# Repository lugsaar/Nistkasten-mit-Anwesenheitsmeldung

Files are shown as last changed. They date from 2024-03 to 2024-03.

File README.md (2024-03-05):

# Nistkasten-mit-Anwesenheitsmeldung
Nistkasten mit LoRaWAN - Nesting Box with LoRaWAN.

Wir wollen im Wald verteilt für die heimischen Vogelarten Nistkästen aufhängen um das Brutverhalten der Vögel unauffällig zu studieren. Wann wird das Nest gebaut, wie entwickeln sich die Jungvögel und wird der Kasten ein zweites Mal belegt. Unser Nistkasten meldet sich über LoRaWAN.  

https://blog.lugsaar.de/posts/2024-02-14-lugposts/

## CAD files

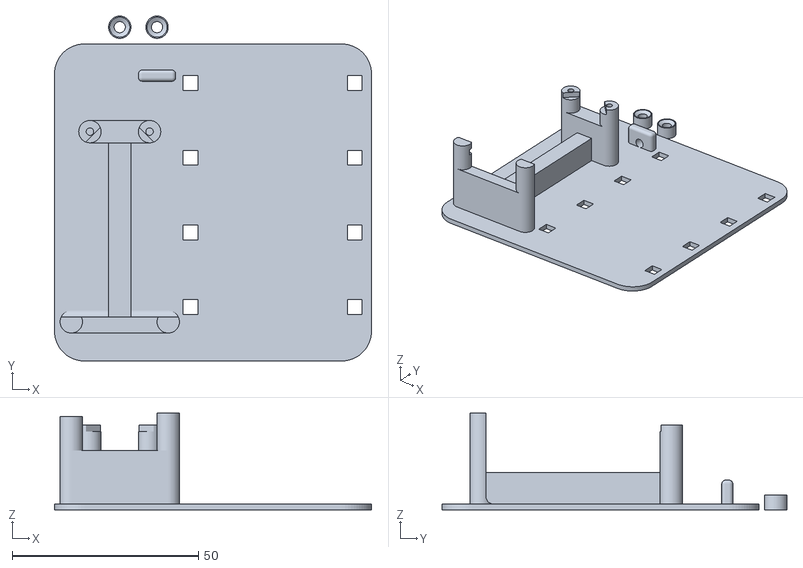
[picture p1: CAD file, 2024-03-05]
3D-printfiles/Heltec_plate_Dose.stl
85.0 x 92.5 x 26.0

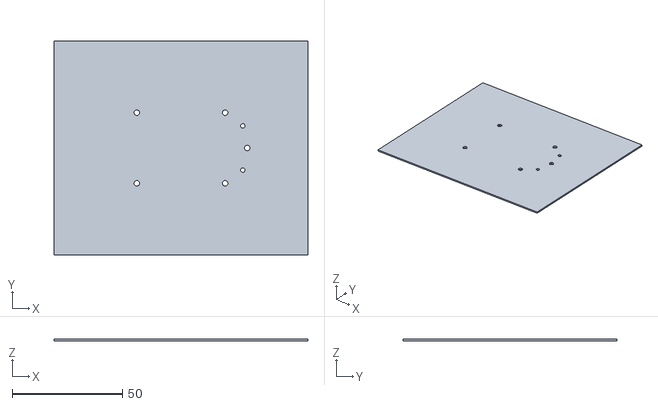
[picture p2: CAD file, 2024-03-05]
3D-printfiles/BohrschablWaegezelle_05.stl
115.0 x 97.0 x 0.8

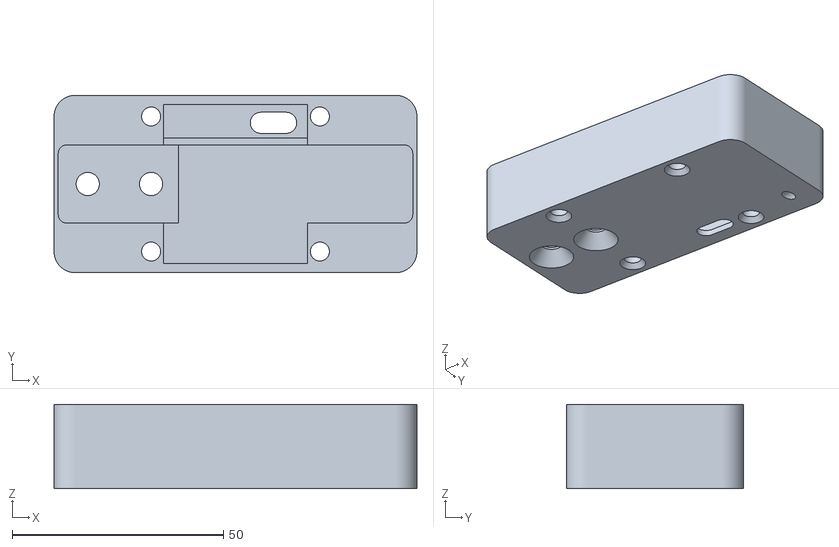
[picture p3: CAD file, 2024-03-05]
3D-printfiles/BodyWaegezelle_05.stl
86.0 x 42.0 x 20.0

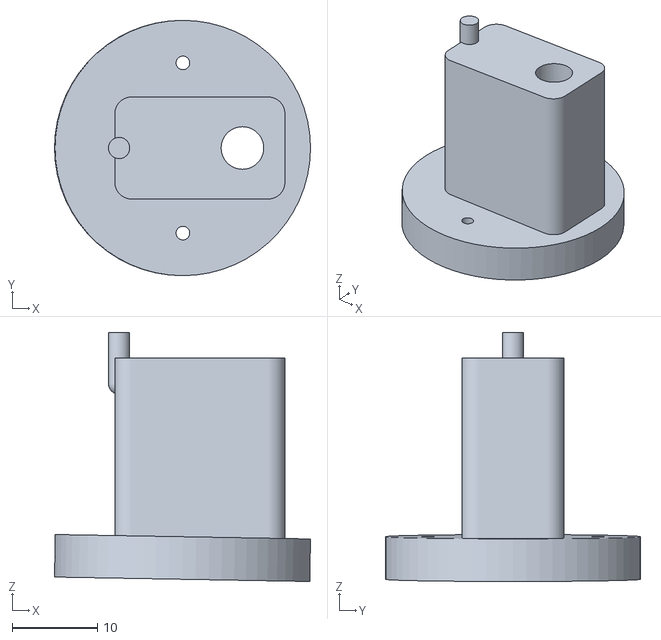
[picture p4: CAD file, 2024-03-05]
3D-printfiles/StuetzeWaegezelle_05.stl
30.1 x 30.0 x 29.3

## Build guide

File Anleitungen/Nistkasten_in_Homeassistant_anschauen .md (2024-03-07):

## So schauen wir uns die Aktivitäten in den Nistkästen in Homeassistant an

#### Einstellungen im TheThingsNetwork

Im TheThingsNetwork finden wir im seitlichen Menü unter Intergrations die Applikation MQTT. Dort wird uns die Serveradresse und der Username angezeigt. In unserem Beispiel waren dies 

    eu1.cloud.thethings.network, Port 1883 und Benutzername nesting@ttn

Mit der Taste generate new API Key erzeugen wir uns das zugehörende Passwort. Nun wechseln wir zu den Live Daten unseres Nistkastens Blaumeisen.

    applikations -> nesting-box-test -> End devices -> blaumeisen -> Live data

und klicken eine der letzten Meldungen an. Es erscheint ein detailierter Json Code. Dort finden wir device_id, application_id und tenant_id.

Um die Devices per mqtt zu abonieren ist die Syntax für den Topic 

    r3/{application id}@{tenant id}/devices, in unserem Fall also r3/nesting@ttn/devices

#### Einstellungen in Homeassistant

In Homeassistant fügen wir die Integration MQTT hinzu. MQTT neu konfigurieren verlangt die oben nachgeschauten Daten Servername, Port, Benutzername und Passwort und unter - auf einen Topic hören - den entsprechenden String.

Jetzt wird die configuration.yaml mit einem Editor manuel angepasst.

In unserer Homeassistant Installation schalten wir in der linken Menüleiste mit Klick auf den Anmeldenamen die erweiterten Optionen frei.
Nun können wir über den Add On Store ssh installieren und in das Terminal wechseln. Die configuration.yaml ist im Verzeichnis config. Wir öffnen sie mit dem Editor nano:

    nano config/configuration.yaml

und ergänzen dieses für unsere beiden Nistkästen.

```
mqtt:
  sensor:
    - name: Rotkehlchen Batterie
      state_topic: "v3/nesting@ttn/devices/rotkehlchen/up"
      value_template: '{{value_json.uplink_message.decoded_payload.batterie_status_in_volt}}'
      unit_of_measurement: "V"
    - name: Rotkehlchen Nestgewicht
      state_topic: "v3/nesting@ttn/devices/rotkehlchen/up"
      value_template: '{{value_json.uplink_message.decoded_payload.nestgewicht_in_gramm}}'
      unit_of_measurement: "g"
    - name: Blaumeisen Batterie
      state_topic: "v3/nesting@ttn/devices/blaumeisen/up"
      value_template: '{{value_json.uplink_message.decoded_payload.batterie_status_in_volt}}'
      unit_of_measurement: "V"
    - name: Blaumeisen Nestgewicht
      state_topic: "v3/nesting@ttn/devices/blaumeisen/up"
      value_template: '{{value_json.uplink_message.decoded_payload.nestgewicht_in_gramm}}'
      unit_of_measurement: "g"
```

Die configuration.yaml ist sehr kritisch bezüglich der richtigen Eingaben und Einrückungen des Codes. Unter 

    Entwicklerwerkzeuge, Reiter YAML -> Konfiguration prüfen 

müssen wir unbedingt feststellen ob wir keinen Fehler gemacht haben, denn dann würde sich Homeassistant nicht mehr starten lassen. 
Wenn alles geklappt hat werden die Nistkästen nach einem Neustart auf der Homeassistant Übersicht auf einer neuen Karte Sensor angezeigt.

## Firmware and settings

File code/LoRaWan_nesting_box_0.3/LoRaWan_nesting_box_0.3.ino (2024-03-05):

/* Nistkasten mit Anwesenheitserkennung
 *
 * Nistkasten mit Heltec WiFi LoRa 32(V3) Node und Wägezelle HX711
 *
 * Funktion:
 * Das Gewicht im Nistkasten wird regelmäßig gemessen
 * und per LoRaWAN an TheThingsNetwork übertragen.
 * An dem Verlauf der Gewichte sehen wir ob und wie
 * der Nistkasten genutzt wird
 * 
 * Ein Projekt der Linux User Group Saar
 * mancas@lug-saar.de
 * dominik@lug-saar.de
 * 
 * 
 * v0.1 neu erstellt
 * v0.2 Kommentare nach DE übersetzt und ergänzt
 * v0.3 Batterie Level auslesen
 */



// Werte für das LoRaWan
// =====================

#include "LoRaWan_APP.h"

// Dies sind die Werte, mit denen unseren Rotkehlchenkasten im TheThingsNetwork angelegt ist
//

//  uint8_t appEui[] = { 0x6E, 0x65, 0x73, 0x74, 0x69, 0x6E, 0x67, 0x0A };
//  uint8_t devEui[] = { 0x70, 0xB3, 0xD5, 0x7E, 0xD0, 0x06, 0x44, 0x73 };
//  uint8_t appKey[] = { 0xBA, 0xC5, 0x2D, 0xAA, 0xEC, 0x79, 0x83, 0x90, 0x9F, 0xC2, 0x56, 0xB7, 0x1C, 0xC0, 0x1D, 0x97 };


// Dies sind die Werte, mit denen unseren Blaumeisenkasten im TheThingsNetwork angelegt ist
// Es wird nur eines der Beispiele geflasht 
// 

 uint8_t appEui[] = { 0x07, 0x00, 0xB3, 0x0D, 0x50, 0x7E, 0x0D, 0x01 };
 uint8_t devEui[] = { 0x70, 0xB3, 0xD5, 0x7E, 0xD0, 0x06, 0x44, 0x90 };
 uint8_t appKey[] = { 0x23, 0x6F, 0xAE, 0x6B, 0x68, 0x2E, 0x5D, 0x26, 0xE9, 0x1A, 0x78, 0xC4, 0x21, 0xC0, 0x0A, 0xD0 };

// Diese ABP Parameter bleiben unverändert
uint8_t nwkSKey[] = { 0x15, 0xb1, 0xd0, 0xef, 0xa4, 0x63, 0xdf, 0xbe, 0x3d, 0x11, 0x18, 0x1e, 0x1e, 0xc7, 0xda,0x85 };
uint8_t appSKey[] = { 0xd7, 0x2c, 0x78, 0x75, 0x8c, 0xdc, 0xca, 0xbf, 0x55, 0xee, 0x4a, 0x77, 0x8d, 0x16, 0xef,0x67 };
uint32_t devAddr =  ( uint32_t )0x007e6ae1;

// LoraWan channelsmask, default channels 0-7*/ 
uint16_t userChannelsMask[6]={ 0x00FF,0x0000,0x0000,0x0000,0x0000,0x0000 };

// LoraWan Region, wird in der Arduiono-IDE bei den Boardeigenschaften gesetzt
LoRaMacRegion_t loraWanRegion = ACTIVE_REGION;

// LoraWan Class, Class A bedeutet nur Senden und kein zeitliches Empfangsfenster öffnen
DeviceClass_t  loraWanClass = CLASS_A;

// Hier wird eingetragen wie oft gesendet wird, Wert in Millisekunden.
// Gemäß Policy dürfen wir nur 1% der Zeit senden. 240000 bedeutet alle 4 Minuten,
// das passt für ein Sendefenster von 2,4 s.
// und ist gut zum Testen. Weniger Energieverbrauch bei nur einer Meldung je Tag 

//uint32_t appTxDutyCycle = 86400000;  // einmal je Tag
//uint32_t appTxDutyCycle = 3600000;  // einmal je Stunde
uint32_t appTxDutyCycle = 240000;      // alle 4 Minuten  

// Wir akzeptieren Auktivierung vom Server
bool overTheAirActivation = true;

// Wir akzeptieren die Adresse von Server
bool loraWanAdr = true;

// Wir senden nur bestätigte Nachrichten
bool isTxConfirmed = true;

// Unser Port
uint8_t appPort = 2;

// Anzahl der Versuche wenn wir keine Bestätigung vom Gateway bekommen
// dabei akzeptieren wir eine Übertragungsreduzierung nach LoRaWAN Specification V1.0.2, chapter 18.4
uint8_t confirmedNbTrials = 4;



// Werte für die Wägezelle
// =======================

#include "HX711.h" //scale
HX711 scale;

uint8_t dataPin = 26;   // Der HX711 dataPin ist am GPIO 26
uint8_t clockPin = 48;  // der HX711 clockPin ist am GPIO 48
int int_nestweight = 0; // Integer-Variable für das Gewicht



// Werte für Auslesen der Batteriespannung
// =======================================

#define VBAT_PIN 1
#define VBAT_READ_CNTRL_PIN 37 // Wir lesen die GPIO aus 
#define ADC_READ_STABILIZE 10 // Wartezeit in ms für die Erfassung

int int_readBatLevel =0; // Variable für die Aufbereitung der payload
float readBatLevel() {
  int analogValue = analogRead(VBAT_PIN);
  float voltage = 0.004376 * analogValue; // Umrechnung der GPIO Werte in Spannung
  return voltage;
}

// Subroutine Aktivieren der Waage und Aufbereiten der Payload
// ===========================================================
static void prepareTxFrame( uint8_t port )
{

// Waage nach dem Energiesparmodus initialisieren  
Serial.begin(115200);

Serial.println("wakeup scale");

scale.begin(dataPin, clockPin); // Anschluss der Kabel übergeben
scale.set_scale(1000.795471);   // Eichwert für leere Waage, wird vorher separat ermittelt, dann eingetragen    
scale.set_offset(4294624289);   // Eichwert für belastete Waage, wird vorher separat ermittelt, dann eingetragen

delay(5000); // Abwarten bis die Waage bereit ist
  
if (scale.is_ready())
  
  {
  Serial.println("scale is ready");
  Serial.println(scale.get_units(1));
  //int_nestweight = abs(scale.get_units(1)*10); // Werte mit einer Nachkommastelle zu Integer aufbereiten nur positive Werte
    int_nestweight = (scale.get_units(1)*10); // Werte mit einer Nachkommastelle zu Integer aufbereiten auch negative Werte
    int_nestweight = 890; //Testwert bei Betrieb ohne Waage 
    if (int_nestweight > 9000) // Werte über 900 g sind Fehlmessungen und werden mit 9999 gekennzeichnet
    {
    int_nestweight = 9999;
    }
  }
  
else
  {
    int_nestweight = 8888; // Die Waage ist nicht bereit, wird mit 8888 gelennzeichnet
    Serial.println("scale not ready");
  }

Serial.println(int_nestweight);

/*
// Initialisierung nach Energiesparmodus
#define VBAT_PIN 1
#define VBAT_READ_CNTRL_PIN 37 // Heltec GPIO to toggle VBatt read connection …
// Also, take care NOT to have ADC read connection
// in OPEN DRAIN when GPIO goes HIGH
#define ADC_READ_STABILIZE 10 // in ms (delay from GPIO control and ADC connections times)
*/

//Batteriespannung
  float v = readBatLevel();
  int_readBatLevel = abs(v*100); //Payload als integer Wert
  Serial.print("Batterielevel ");
  Serial.println(int_readBatLevel);

// Die Payload wird verpackt
appDataSize = 4; //für 16 bit integer
appData[0] = int_nestweight >> 8;    // Schreiben der ersten 8 bit ans Ende
appData[1] = int_nestweight;         // Nachschieben der zweiten 8 bit
appData[2] = int_readBatLevel >> 8;  
appData[3] = int_readBatLevel;

}



// Diese setup Schleife wird nur beim ersten Aufruf des Programmes durchlaufen
// =====================================================================================

void setup() {
  Serial.begin(115200);
  
  Mcu.begin();
  deviceState = DEVICE_STATE_INIT;

  scale.begin(dataPin, clockPin);
  scale.set_scale(1000.795471);       
  scale.set_offset(4294624289);

  
// Die Wägezelle wird auch in ihrer Subroutine aktiviert
// dies ist notwendig da wir aus dem Energiesparmodus kommen 

// Start Auslesen Batterielevel
  pinMode(VBAT_READ_CNTRL_PIN,OUTPUT);
  digitalWrite(VBAT_READ_CNTRL_PIN, LOW);


}





// Diese Schleife wird immer abgearbeitet
// ======================================
void loop()

{
  //prepareTxFrame( appPort )
  
  switch( deviceState )
  {
    case DEVICE_STATE_INIT:
    {
#if(LORAWAN_DEVEUI_AUTO)
      LoRaWAN.generateDeveuiByChipID();
#endif
      LoRaWAN.init(loraWanClass,loraWanRegion);
      break;
    }
    case DEVICE_STATE_JOIN:
    {
      LoRaWAN.join();
      break;
    }
    case DEVICE_STATE_SEND:
    {
      prepareTxFrame( appPort ); // Aufrufen der Waage und Packen der  Payload
      LoRaWAN.send();            // Senden
      deviceState = DEVICE_STATE_CYCLE;
      break;
    }
    case DEVICE_STATE_CYCLE:
    {
      // Schedule next packet transmission
      txDutyCycleTime = appTxDutyCycle + randr( -APP_TX_DUTYCYCLE_RND, APP_TX_DUTYCYCLE_RND );
      LoRaWAN.cycle(txDutyCycleTime);
      deviceState = DEVICE_STATE_SLEEP;
      break;
    }
    case DEVICE_STATE_SLEEP:
    {
      LoRaWAN.sleep(loraWanClass);
      break;
    }
    default:
    {
      deviceState = DEVICE_STATE_INIT;
      break;
    }
  }
}


/*
// Passender Payload Decoder 
// =========================

// Diese Java-Funktion nicht hier aktivieren sonder bei TheThingsNetwork einrichten.

  function decodeUplink(input) {
  
  var weight = input.bytes[0] << 8 | input.bytes[1];
  var errormessage = 'fehlmessung';
  var batt =   input.bytes[2] << 8 | input.bytes[3];
  
  if ( weight < 1000 ) {
    return {
      data: {
        nestgewicht_in_gramm: weight/10,
        batterie_status_in_volt: batt/100
      }
    };
  }
    
  else {
    return {
      data: {
        nestgewicht_in_gramm: errormessage
      } 
    };
  }

}
*/
